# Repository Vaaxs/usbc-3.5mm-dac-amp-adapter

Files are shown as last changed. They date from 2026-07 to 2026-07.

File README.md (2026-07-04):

# usbc-3.5mm-dac-amp-adapter
Project for Stasis, a DAC amp that is also an adapter, to go from USB-C to 3.5mm.

## How it works

USB-C in → PCM2704CDB DAC → 3.5mm TRS out. The chip enumerates as a standard USB Audio Class device, so there is no firmware or drivers needed.

Specs

| Parameter | Value |
|---|---|
| DAC IC | Texas Instruments PCM2704CDB |
| Package | SSOP-28, 0.65mm pitch |
| USB | Full-speed USB 2.0 via USB-C receptacle |
| Output | 3.5mm TRS (stereo, no mic) |
| Sample rate | Up to 48 kHz, 16-bit |
| Crystal | 12 MHz ABM8-12.000MHZ-12-B1U-T |
| Power | Bus-powered from USB (500mA max) |
| Protection | 500mA polyfuse on VBUS |
| Board size | ~72mm × 22mm |
| Mounting | Two M2 mounting holes |

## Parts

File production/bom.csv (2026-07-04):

Designator | Footprint | Quantity | Value | LCSC Part #
C1, C6 | 0805 | 2 | 10uF
C10, C9 | 0402 | 2 | 22nF
C14, C15 | 0402 | 2 | 18pf
C2, C3, C4, C5 | 0402 | 4 | 1uF
C7, C8 | 1210 | 2 | 100uF
F1 | 0805 | 1 | Polyfuse
J1 | USB_C_Receptacle_HRO_TYPE-C-31-M-12 | 1 | USB_C_Receptacle_USB2.0_16P
J2 | Jack_3.5mm_CUI_SJ-3523-SMT_Horizontal | 1 | AudioJack3
R1, R2 | 0402 | 2 | 16Ω
R3 | 0805 | 1 | 3.3kΩ
R4 | 0402 | 1 | 10kΩ
R5 | 0402 | 1 | 1MΩ
R6, R7 | 0402 | 2 | 5.1k
U1 | SOP65P780X200-28N | 1 | PCM2704CDB
Y1 | Crystal_SMD_3225-4Pin_3.2x2.5mm | 1 | Crystal_GND24

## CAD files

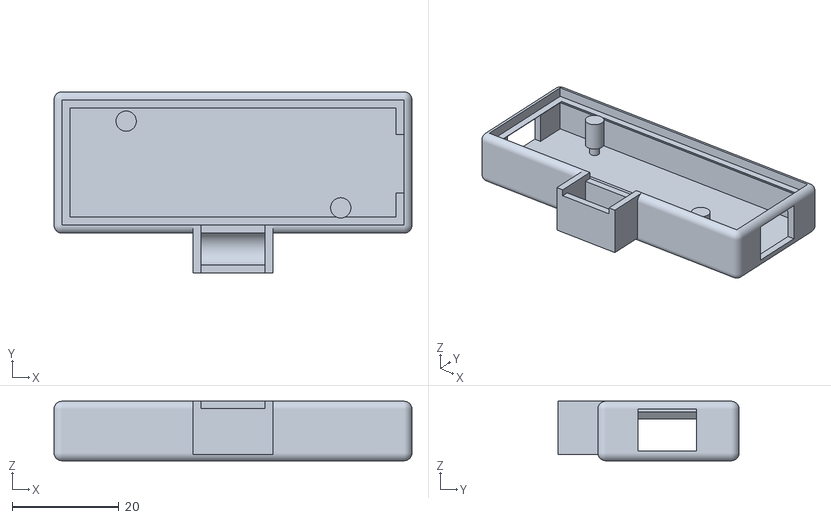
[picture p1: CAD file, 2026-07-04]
case.stl
67.1 x 34.0 x 11.2

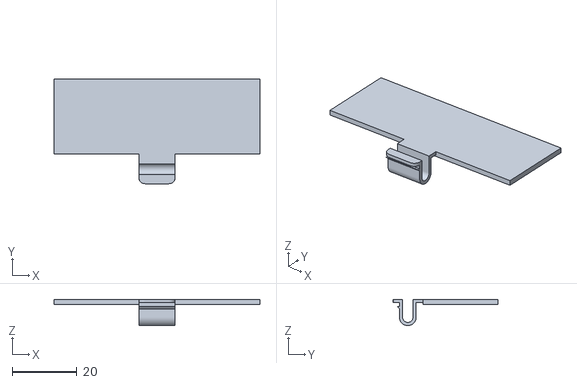
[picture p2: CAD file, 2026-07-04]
compartment_door.stl
63.7 x 32.3 x 8.10

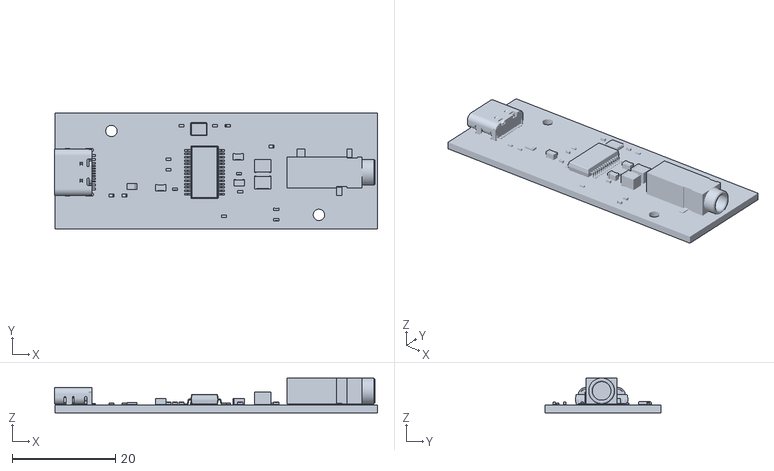
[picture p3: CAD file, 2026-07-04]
board.stl
62.6 x 22.5 x 6.76

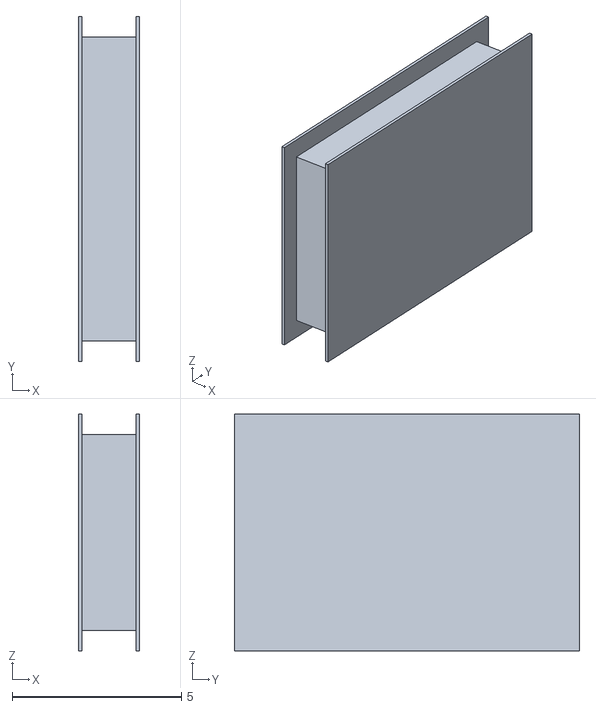
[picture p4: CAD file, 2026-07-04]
waterproof_SJ3523SMTTR.stl
1.80 x 10.2 x 7.00

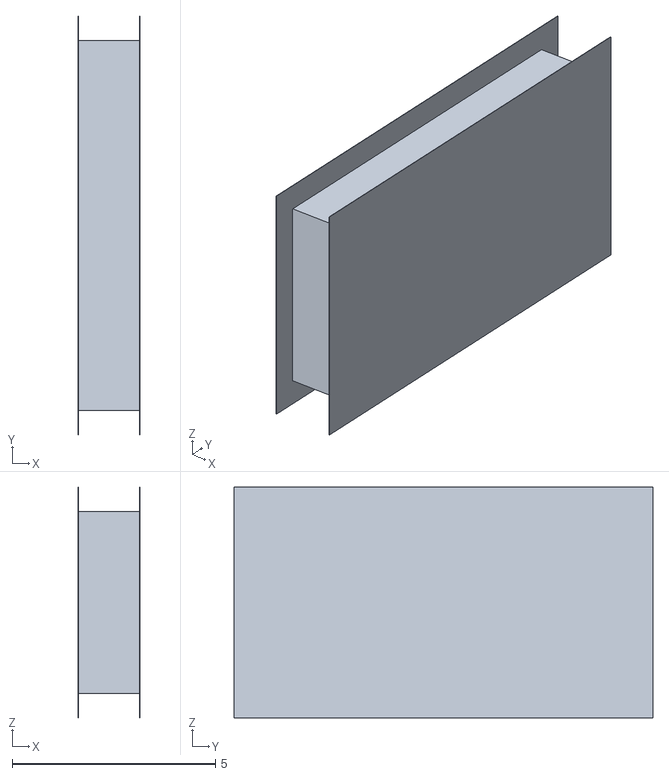
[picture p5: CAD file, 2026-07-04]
waterproof_TYPEC31M12.stl
1.53 x 10.3 x 5.68

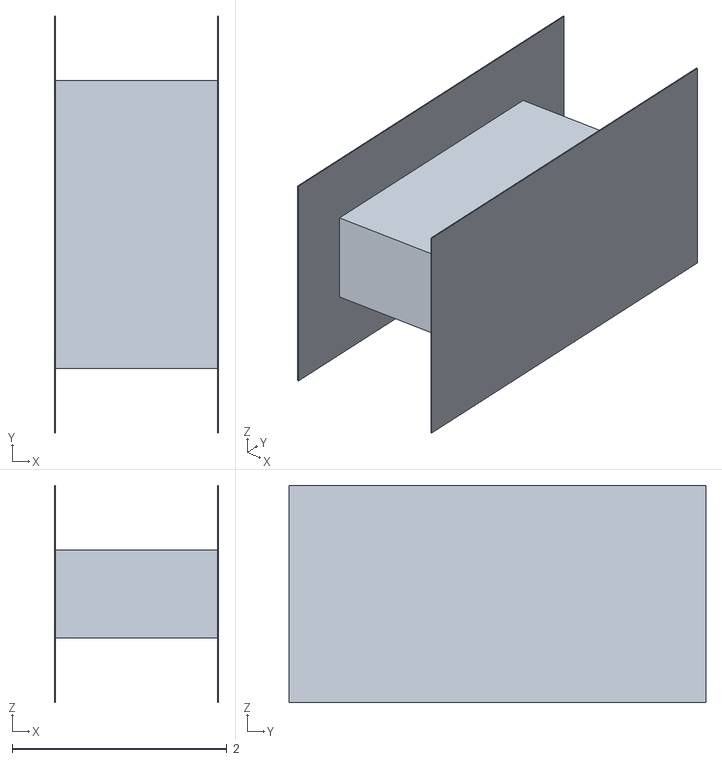
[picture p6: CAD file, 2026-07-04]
waterproof_x.stl
1.53 x 3.88 x 2.02

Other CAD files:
pcb3dmodel.step

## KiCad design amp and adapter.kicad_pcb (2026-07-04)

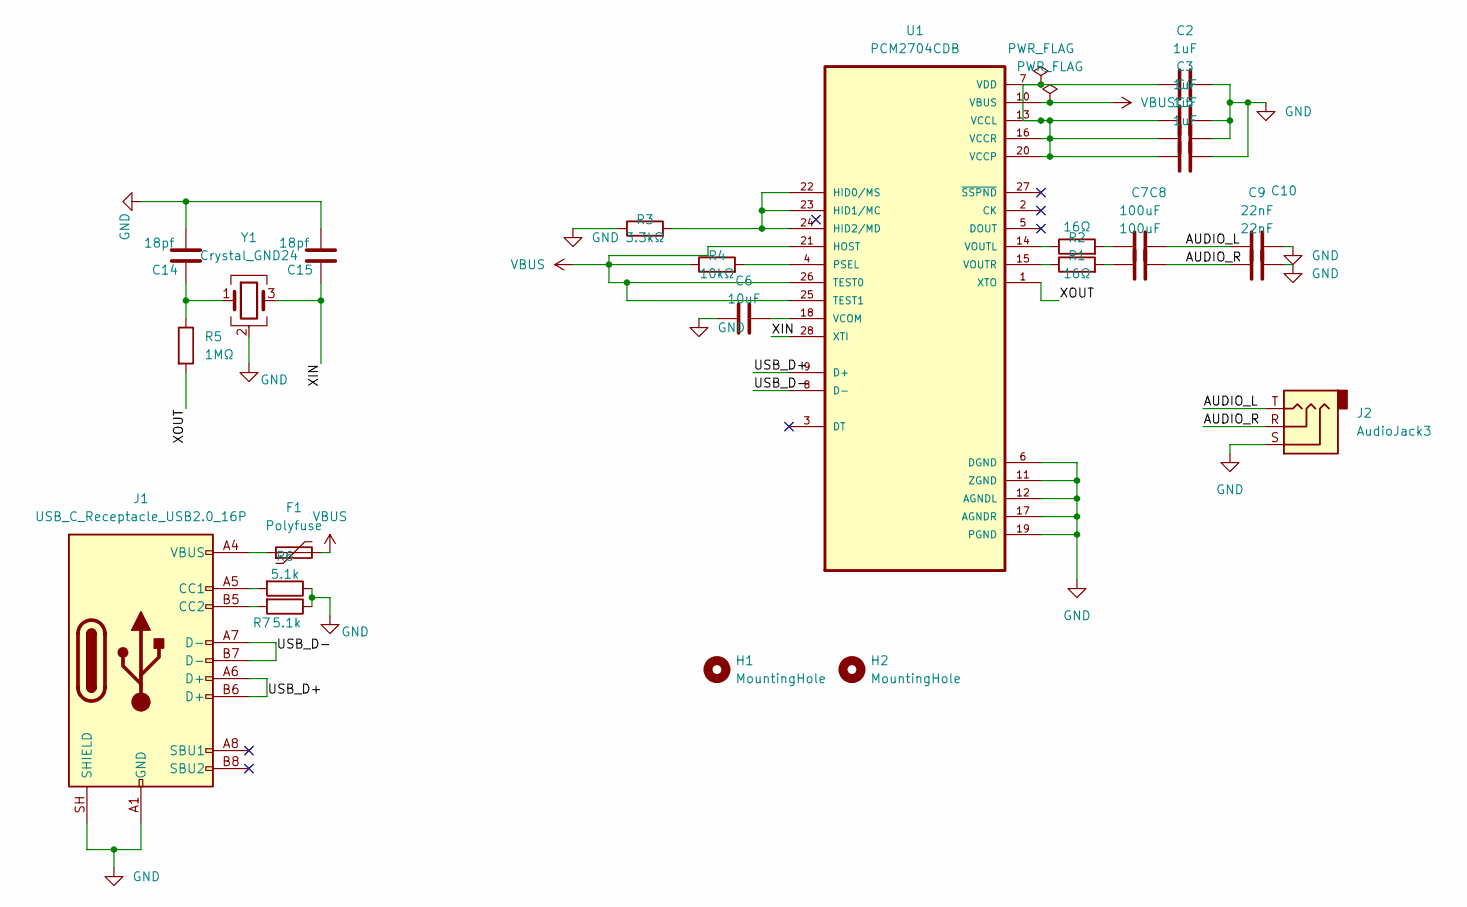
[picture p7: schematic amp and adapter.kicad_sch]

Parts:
C2, C3, C4, C5: 1uF; C_0402_1005Metric; LCSC Part # C52923
C6: 10uF; C_0805_2012Metric; LCSC Part # C15850
C7, C8: 100uF; C_1210_3225Metric; LCSC Part # C15008
C9, C10: 22nF; C_0402_1005Metric; LCSC Part # C1534
C14, C15: 18pf; C_0402_1005Metric; LCSC Part # C1548
F1: Polyfuse; Fuse_0805_2012Metric; LCSC Part # C70077
H1, H2: MountingHole; MountingHole_2.2mm_M2
J1: USB_C_Receptacle_USB2.0_16P; USB_C_Receptacle_HRO_TYPE-C-31-M-12; LCSC Part # C165948
J2: AudioJack3; Jack_3.5mm_CUI_SJ-3523-SMT_Horizontal; LCSC Part # C4991872
R1, R2: 16Ω; R_0402_1005Metric; LCSC Part # C25095
R3: 3.3kΩ; R_0402_1005Metric; LCSC Part # C25890
R4: 10kΩ; R_0402_1005Metric; LCSC Part # C25744
R5: 1MΩ; R_0402_1005Metric; LCSC Part # C26083
R6, R7: 5.1k; R_0402_1005Metric
U1: PCM2704CDB; SOP65P780X200-28N; LCSC Part # C5964
Y1: Crystal_GND24; Crystal_SMD_3225-4Pin_3.2x2.5mm; LCSC Part # C9002

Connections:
/AUDIO_L: C7.2, C9.2, J2.T
/AUDIO_R: C8.2, C10.2, J2.R
/USB_D+: J1.A6 (D+), J1.B6 (D+), U1.9 (D+)
/USB_D-: J1.A7 (D-), J1.B7 (D-), U1.8 (D-)
/XIN: C15.1, U1.28 (XTI), Y1.3
/XOUT: R5.2, U1.1 (XTO)
GND: C2.2, C3.2, C4.2, C5.2, C6.1, C9.1, C10.1, C14.2, C15.2, J1.A1 (GND), J1.A12 (GND), J1.B1 (GND), J1.B12 (GND), J1.SH (SHIELD), J2.S, R3.1, R6.1, R7.1, U1.6 (DGND), U1.11 (ZGND), U1.12 (AGNDL), U1.17 (AGNDR), U1.19 (PGND), Y1.2 (G), Y1.4 (G)
unnamed: C7.1, R2.2
unnamed: C8.1, R1.2
unnamed: C14.1, R5.1, Y1.1
unnamed: F1.1, J1.A4 (VBUS), J1.A9 (VBUS), J1.B4 (VBUS), J1.B9 (VBUS)
unnamed: J1.A5 (CC1), R6.2
unnamed: J1.B5 (CC2), R7.2
unnamed: R3.2, U1.22 (HID0/MS), U1.23 (HID1/MC), U1.24 (HID2/MD)
unnamed: R4.2, U1.4 (PSEL)
unnamed: C2.1, C3.1, C4.1, C5.1, U1.7 (VDD), U1.13 (VCCL), U1.16 (VCCR), U1.20 (VCCP)
unnamed: C6.2, U1.18 (VCOM)
unnamed: R2.1, U1.14 (VOUTL)
unnamed: R1.1, U1.15 (VOUTR)

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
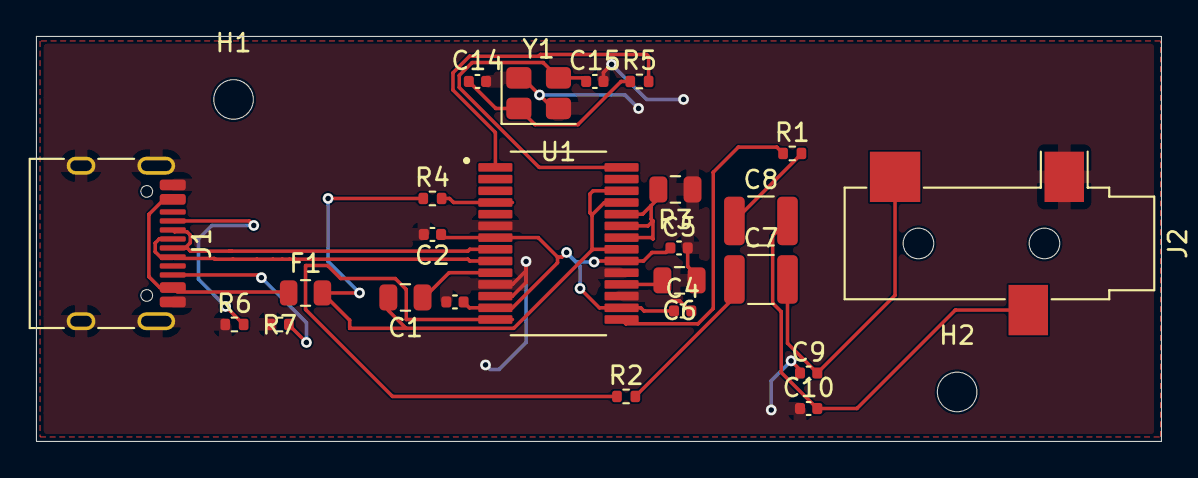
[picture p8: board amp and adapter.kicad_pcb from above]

Board: 2 copper layers, 62.5 x 22.5 mm, 26 parts (0 on the bottom side), 21 nets.

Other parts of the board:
C1: 10uF; C_0805_2012Metric

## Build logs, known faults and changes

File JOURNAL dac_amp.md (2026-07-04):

<!--
  This journal is auto generated by Stasis.
-->

# 7/1/2026 2 AM - 3d Model

_Time spent: 2h_


3d Model for the case, I went through Fusion 360, and that really didn't work, so I went through https://paramecad.com/models/casemaker
And it was a very helpful tool for me, so now I'm practically finished.



# 6/22/2026 7 AM - Fixing PCB Errors

_Time spent: 2.5h_

I fixed all the DRC errors on the PCB. I went to the KiCad Reddit, and lots of people helped with issues that were kinda dumb, but I think I understand where I went wrong with them now.

When I started, my DRC looked like this
, but I had to change some things, like removing the capacitor from my schematic where the VBUS pin was, as well as removing the global VBUS label because it was confusing and restricted my VBUS to always go through the polyfuse instead of only the one time it needed to. 


I wired the 3.3 Volt components together. I didn't realize I needed to wire them, even though I saw the ratwires and thought it was implicitly connected. I don't know why I did, but it made sense to me at the time, lol. But I connected those, and it worked out.


I also added the copper pour to the back layer just for convenience and to allow me to connect certain parts to the ground when they're isolated from the top copper pour.

I also connected these two grounds together because the bottom one was isolated from the copper pour, and that did the trick and removed all of my DRC errors. 



The warnings are negligent its all just silkscreen stuff, which I don't believe I need to worry about right now. There's been a big gap in my work on this project because of school lol, but tomorrow I want to ACTUALLY do the 3d section and get a casing done for this and then send it to get approved and actually made fr.







# 5/7/2026 11 PM - PCB Wiring

_Time spent: 5h_

Working on the wiring of the PCB

This is how I set everything up at first 

But this didn't stay like that for long.

I had to make a layer of copper ground, which was confusing to do for the first time, but I got it down. Then I wired my VBUS to my USB-C and the DAC. I had some issues with the wiring not being straight, but I fixed that.



Then I worked on my crystal oscillator


 


This one went fine; the wiring was pretty basic, although I had an issue with the copper ground. It worked out after I redid it, and now I know I should press B after each change so that the copper pour gets refreshed.

Here I wired my PCM; this was pretty straightforward



After I wired my D+ and D- from the USB-C to the PCM



I had some issues with making the wire straight, with the ____ paths thing, but after a bit it worked fine but I still do not know how it works, because for me it works after a million tries only.

Then I ran DRC before I continued with the rest of the PCB, just so that I could fix any issues before they piled up.

I got these errors 




And with that, I had to go to the solder mask page and tick "Allow bridged solder mask apertures between pads within footprints." For the other error, I had to change my track width and clearance, and that fixed that issue.

I've had some issues with wiring that took me a while to fix, but after a bit, I finished it all.


I'm going to run DRC and fix all the issues that come along.

Ran DRC, fixed all issues and now I am left with this.














# 4/26/2026 10 PM - Schematic Finished FR, Footprints and PCB Layout

_Time spent: 2.25h_

The first thing I did was work on the footprints for my build, which was pretty simple since mostly everything I have is either in the base KiCad libraries or my PCM, which was imported, but I did have a slight issue importing the footprint for it, and for the audio jack I changed it to a TRS since I didnt need the TRRS function and it was simpler, but than that it worked out fine.



I ran ERC and got a few errors, but nothing was really a big deal. I just had to put power flags in a few places, and also put no connection markers on the empty connections. 

(ignore the mounting holes for now, I'll get into that.)

After that, I laid out my PCB and just put things in places where they belonged, 

But after a bit, I realized that for the scope of my project, I would need to put this in a case of some kind, and with that, I would need mounting holes in the build so that it could be secure in the case where it is. SO I added those to both my schematic and PCB, which did make the layout a bit more complex, but I got it done. 



Next time I work on this, I want to finish the wiring and get started on the 3D models for stuff and the 3D model for a case in Fusion 360.






# 4/26/2026 10 PM - Schematic

_Time spent: 3.5h_

This was my first time really finishing a schematic by myself, and here it is.



I looked up the datasheet for the PCM and referenced some other projects to fill out the schematic, along with some help from Google, but it was pretty hard to do the first time around, and I'm not very confident that it is wired correctly, so if I do have to go back and rewire some things, that'll be alright. 

For the USB-C, I copied what I used over from my devboard project since all I really need it for is an adapter, and that's all that it is right now with no buttons or anything. The devboard tutorial included an MCP1700x-330xxTT, which is a voltage regulator, but I don't know if I need it for this project since it does just say VBUS, so I'm going to ask in stasis and see if this is fine, but there's a chance that it is not.

For my crystal oscillator, I was confused for a while on what I even had to do for the XTI and XTO but I realized that it was like the same thing as the XOUT and XIN for the devboard project, so I copied it over and changed the numbers of the resistors and capacitors (hopefully they work fine), but as of now I'm not really sure if I need the two grounds but its fine.

For the 3.5mm output, I literally just looked up TRRS (which you have to do to get the audio jacks in KiCad for some reason), which is like the 4-input format for 3.5mm containing right, left, microphone, and ground. Right now, I haven't figured out how to wire it with microphone capabilities, but I'm not entirely sure if I want it to do that. I may think about adding that at a later date.

Actually, I'm just realizing the DAC part I selected, PCM2704CDB, is read only sooo I guess there will be no audio input capabilities. That's fine, I'm using this for my IEM set anyway.



After I want to make my PCB, make a 3d model in fusion for the amp and adapter then submit probably.




# 4/20/2026 3 AM - Planning, Finding Parts, and Starting schematic

_Time spent: 1.5h_

I started with the devboard project, but it got a tad bit boring, and the tutorial was a bit weird for me, so I decided to pivot to something a little bit more straightforward but also somewhat hard.

I started looking for a DAC amp, and what was reccomended to me was the PCM2704CDB by Texas Instruments, so I had to import that. After that I just pulled up the data sheet and started wiring things, and this is what I have so far.





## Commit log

2026-07-04 Prod Files, PCB, and Schematic.
    Prod files, PCB, Schematic, and 3D Model.
    [amp and adapter.kicad_pcb, amp and adapter.kicad_sch, bom.csv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]
2026-07-04 3D Casing Upload
    [board.stl, case.stl, compartment_door.stl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]
